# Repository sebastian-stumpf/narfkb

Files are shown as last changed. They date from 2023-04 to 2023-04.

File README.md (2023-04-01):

# narfkb

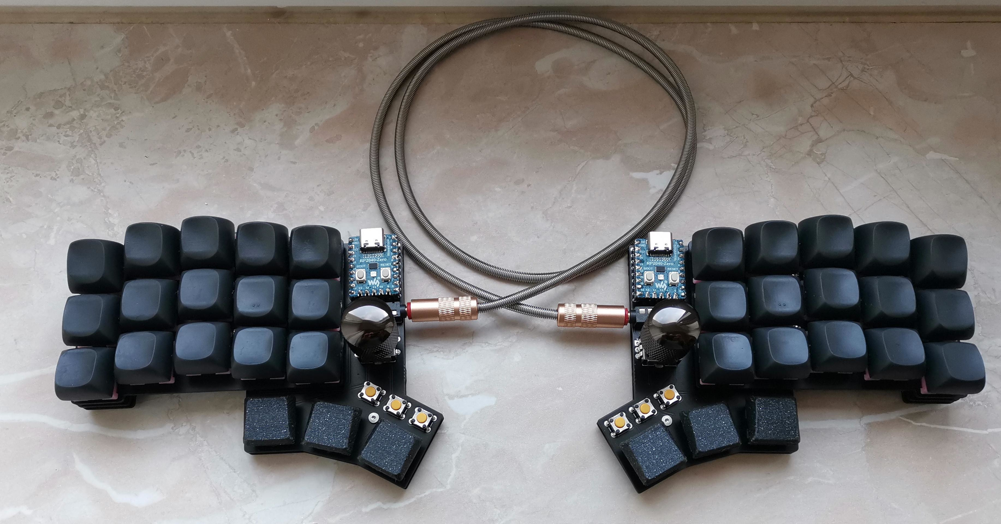
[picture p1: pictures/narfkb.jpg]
narfkb


[More pictures here](https://imgur.com/a/LNFxImS)

## Attention

I'm a hobbyist/amateur at best. So there may be things that aren't optimized. For example the routing on the PCB is a hot mess
and the spacers between the plate should be 3.4mm but there aren't any spacers that size. That being said I've had the files
in the `gerbers/` directory manufactured at JLC with 1.6mm size and they work just fine with the code provided in the `qmk/`
directory. So if you decide to use this, then please be advised that I'm not providing any sort of liability and you should
exercise some caution.

## BOM

| Quantity  | Item | Comment |
| --- | --- | --- |
| 2 | Waveshare RP2040-Zero | |
| 2 | IC-Sockets for MCU | Optional but recommended |
| 2 | TRRS Sockets | |
| 44 | 1N4148 SOD123 diodes | |
| 30 | MX Hotswap Sockets | |
| 6 | Choc Hotswap Sockets | |
| 2 | EC11 Encoders | |
| 6 | Omrom 6mm Tact switches | B3F-1002 |
| 30 | MX Switches + Keycaps | |
| 6 | Choc Switches + Keycaps | |
| 12 | M2 Screws, Nuts, Bolts and Spacers | |

## Feedback

I'm always happy to hear your opinions about this and if you decide to build this board then please do send me a picture of it.

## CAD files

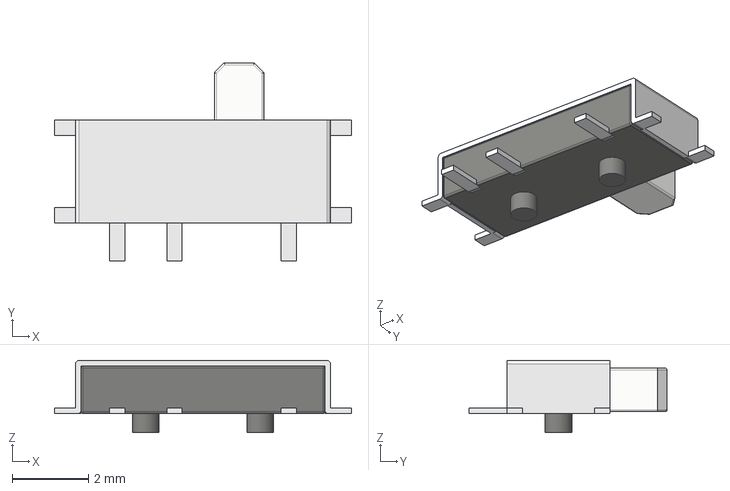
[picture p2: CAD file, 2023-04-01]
pcb/sepp/models/MSK12C02.step
7.80 x 5.20 x 1.90 mm

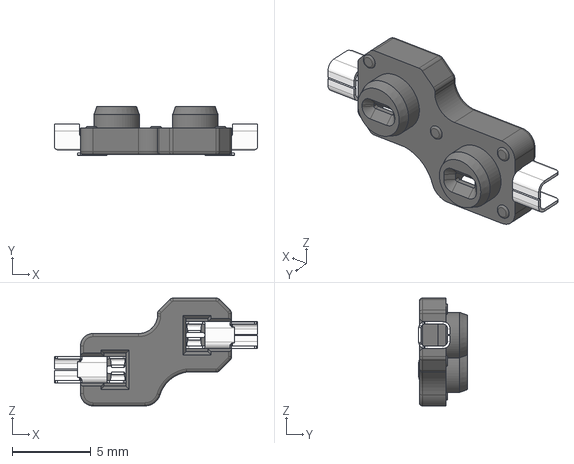
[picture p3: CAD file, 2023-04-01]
pcb/sepp/models/HS_Kailh_Choc.step
12.9 x 3.09 x 6.85 mm
pin x 2
socket

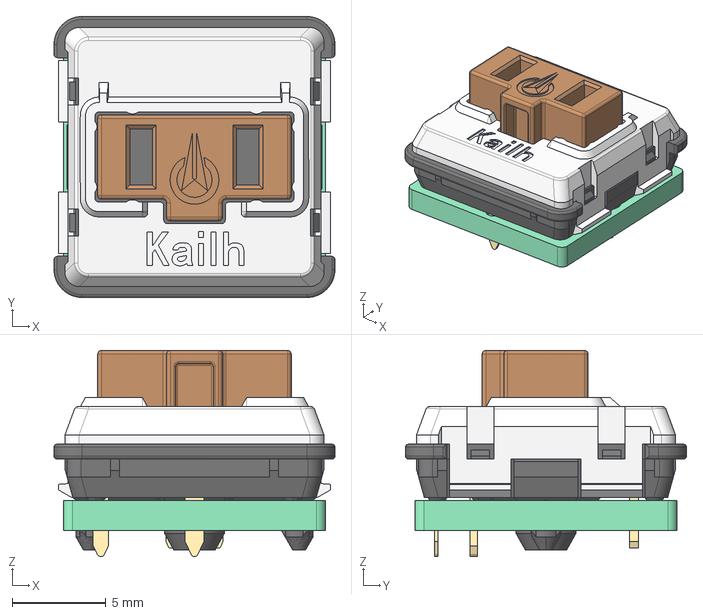
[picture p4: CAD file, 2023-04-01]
pcb/sepp/models/pg1350.step
15.0 x 15.0 x 11.0 mm

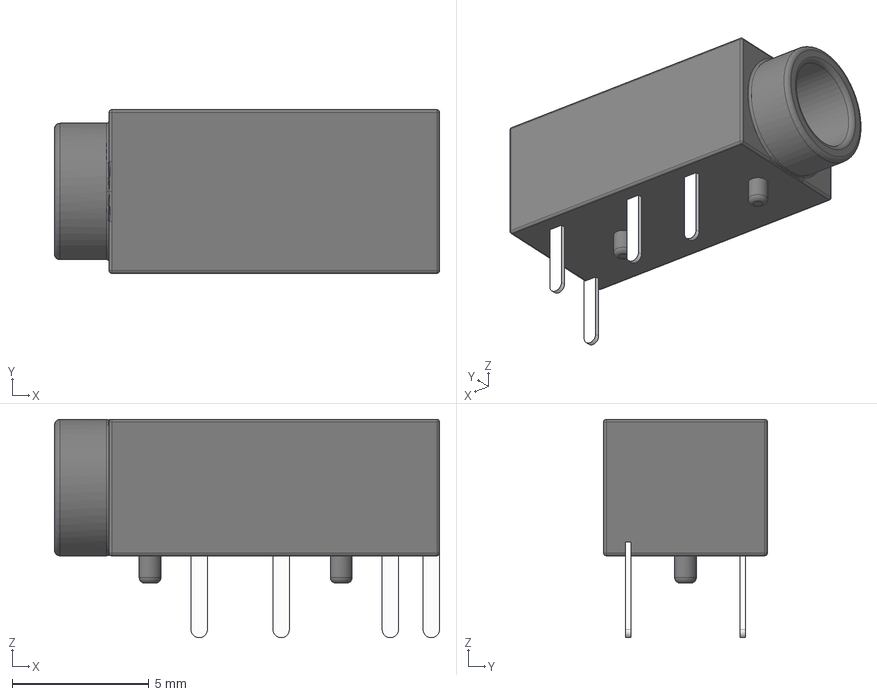
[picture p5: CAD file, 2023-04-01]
pcb/sepp/models/CON_MJ-4PP-9.step
14.1 x 6.00 x 8.00 mm

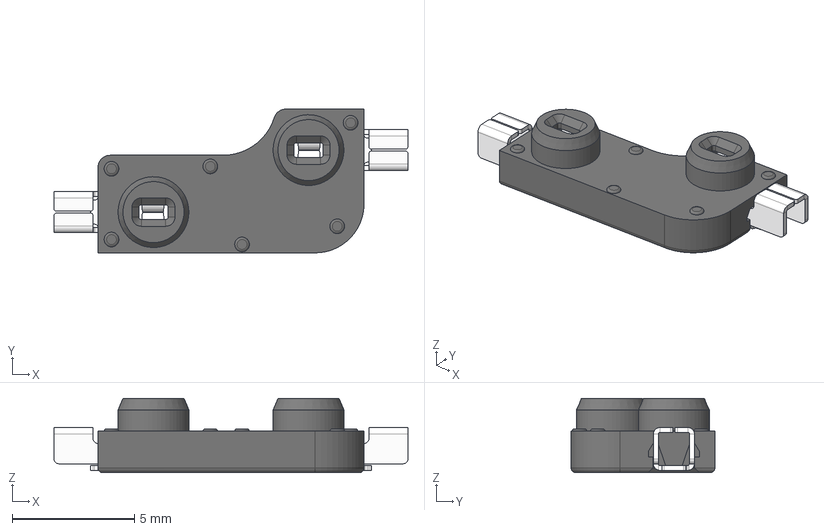
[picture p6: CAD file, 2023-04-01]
pcb/sepp/models/HS_Kailh_MX.step
14.5 x 5.89 x 3.05 mm
Contact x 2

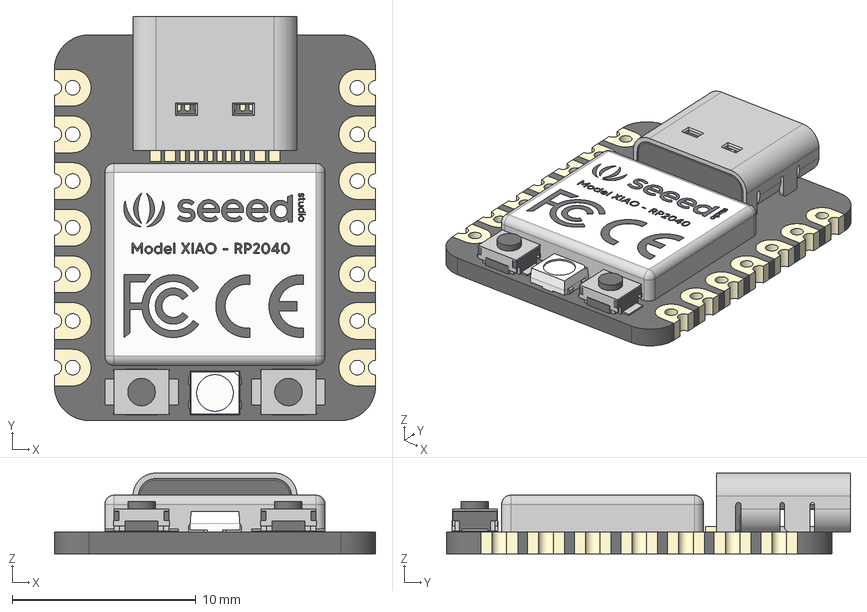
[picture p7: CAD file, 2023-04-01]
pcb/sepp/models/xiao_rp2040.step
17.5 x 22.0 x 4.40 mm
type-c v2
smd_button v3
DOUT
DIN
VSS
VDD
smd_button v3(Mirror)

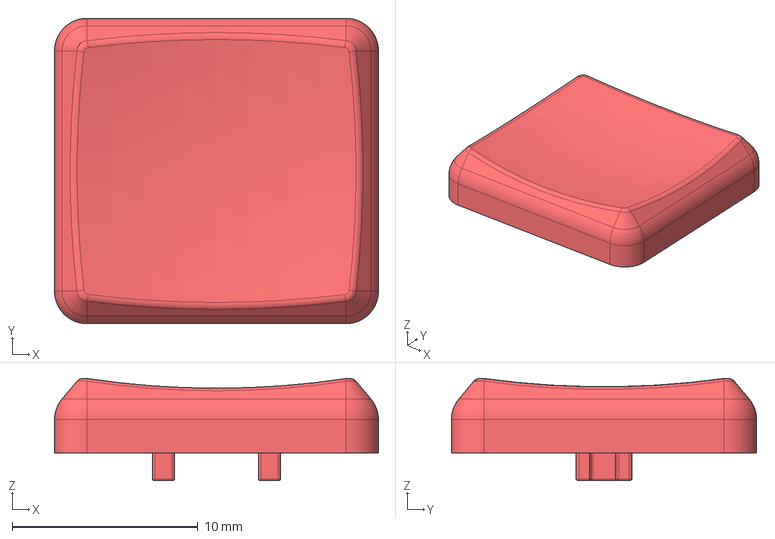
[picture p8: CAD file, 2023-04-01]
pcb/sepp/models/MBK-1u.step
17.4 x 16.4 x 5.52 mm

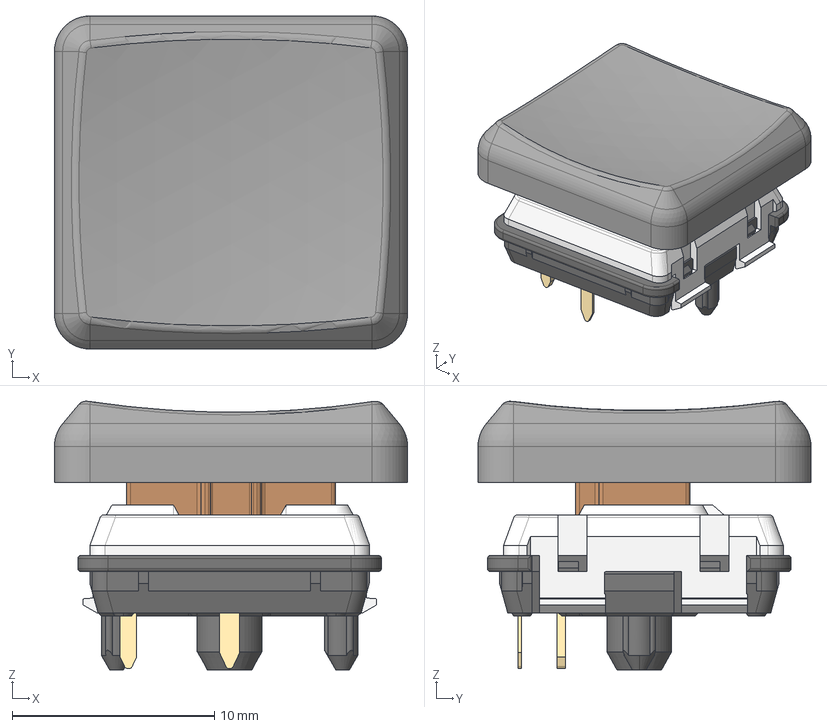
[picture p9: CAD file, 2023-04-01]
pcb/sepp/models/pg1350-mbk.step
17.4 x 16.4 x 13.3 mm
(Unsaved)
Document x 5

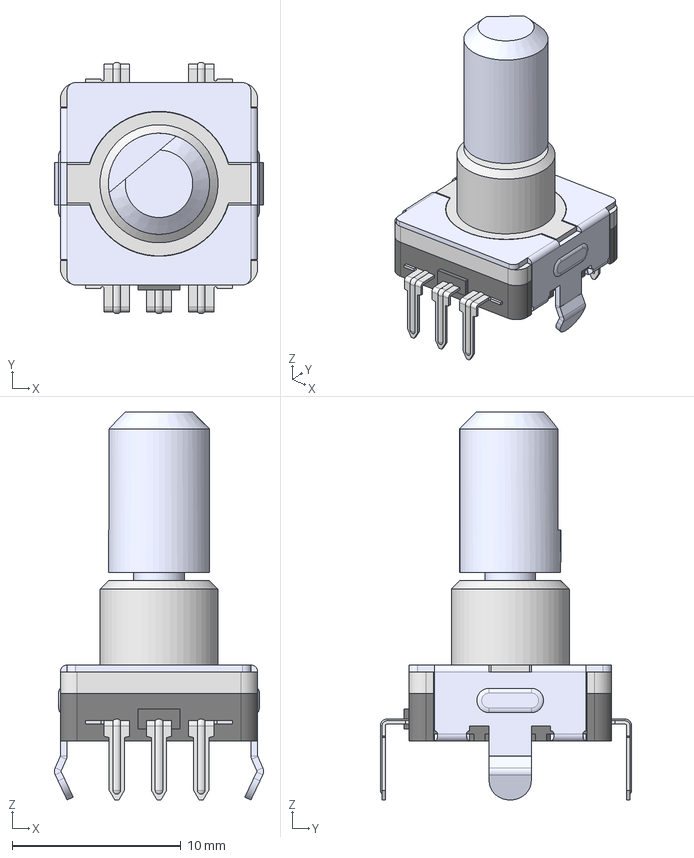
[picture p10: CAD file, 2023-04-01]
pcb/sepp/models/EC11-THT-15F-black.step
12.4 x 14.9 x 23.0 mm
Lb5
15F
EC11-Housing-THT

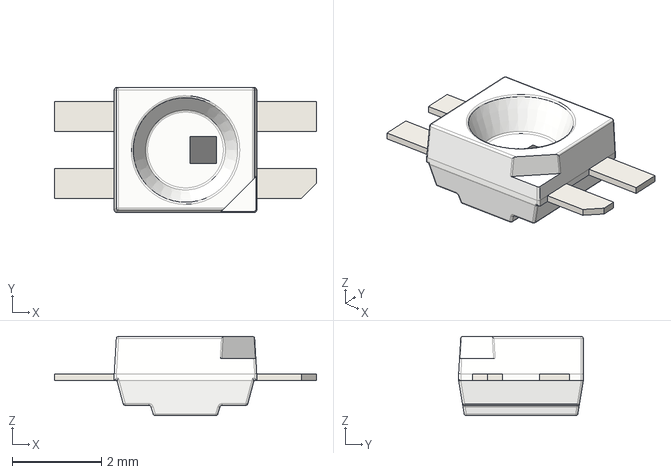
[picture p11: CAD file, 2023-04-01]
pcb/sepp/models/LED_SK6812MINI-E.step
5.88 x 2.80 x 1.78 mm

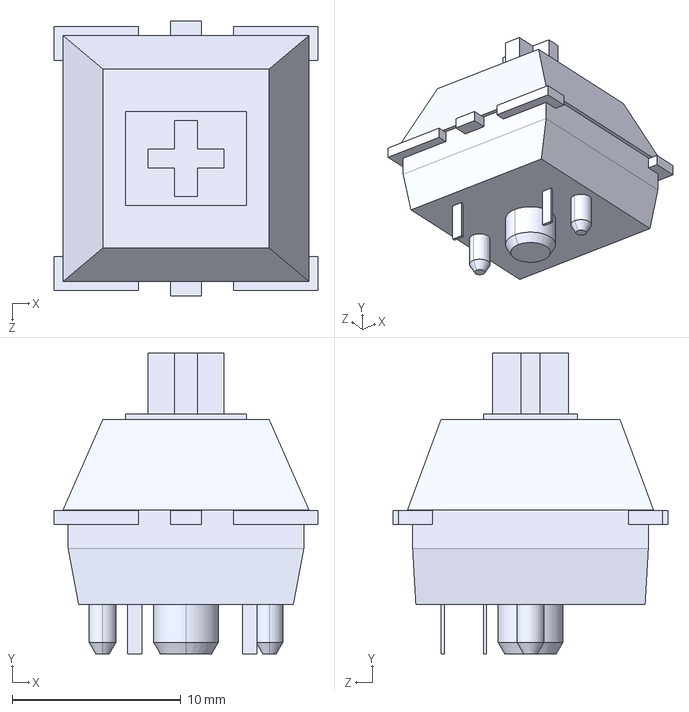
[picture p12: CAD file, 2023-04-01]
pcb/sepp/models/cherry mx.STEP
15.6 x 17.9 x 16.3 mm

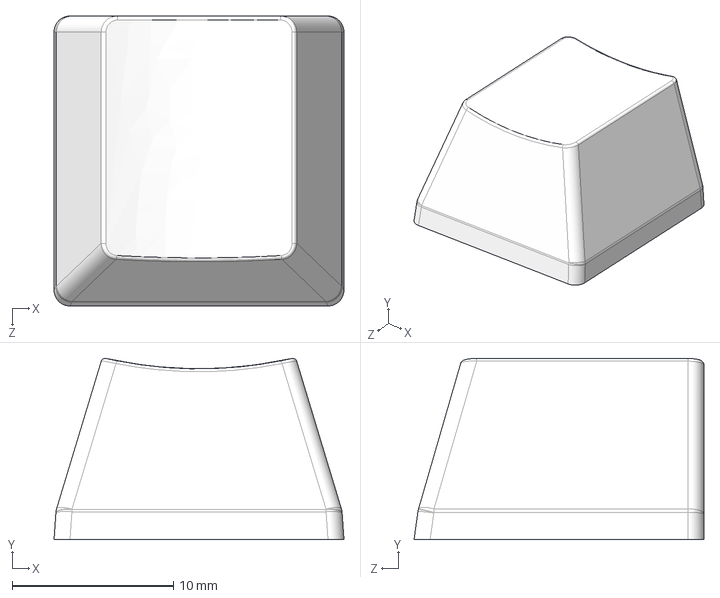
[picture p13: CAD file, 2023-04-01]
pcb/sepp/models/mx_kecap.step
18.0 x 11.3 x 18.0 mm

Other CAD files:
pcb/sepp/models/SW_MSK12C02.step

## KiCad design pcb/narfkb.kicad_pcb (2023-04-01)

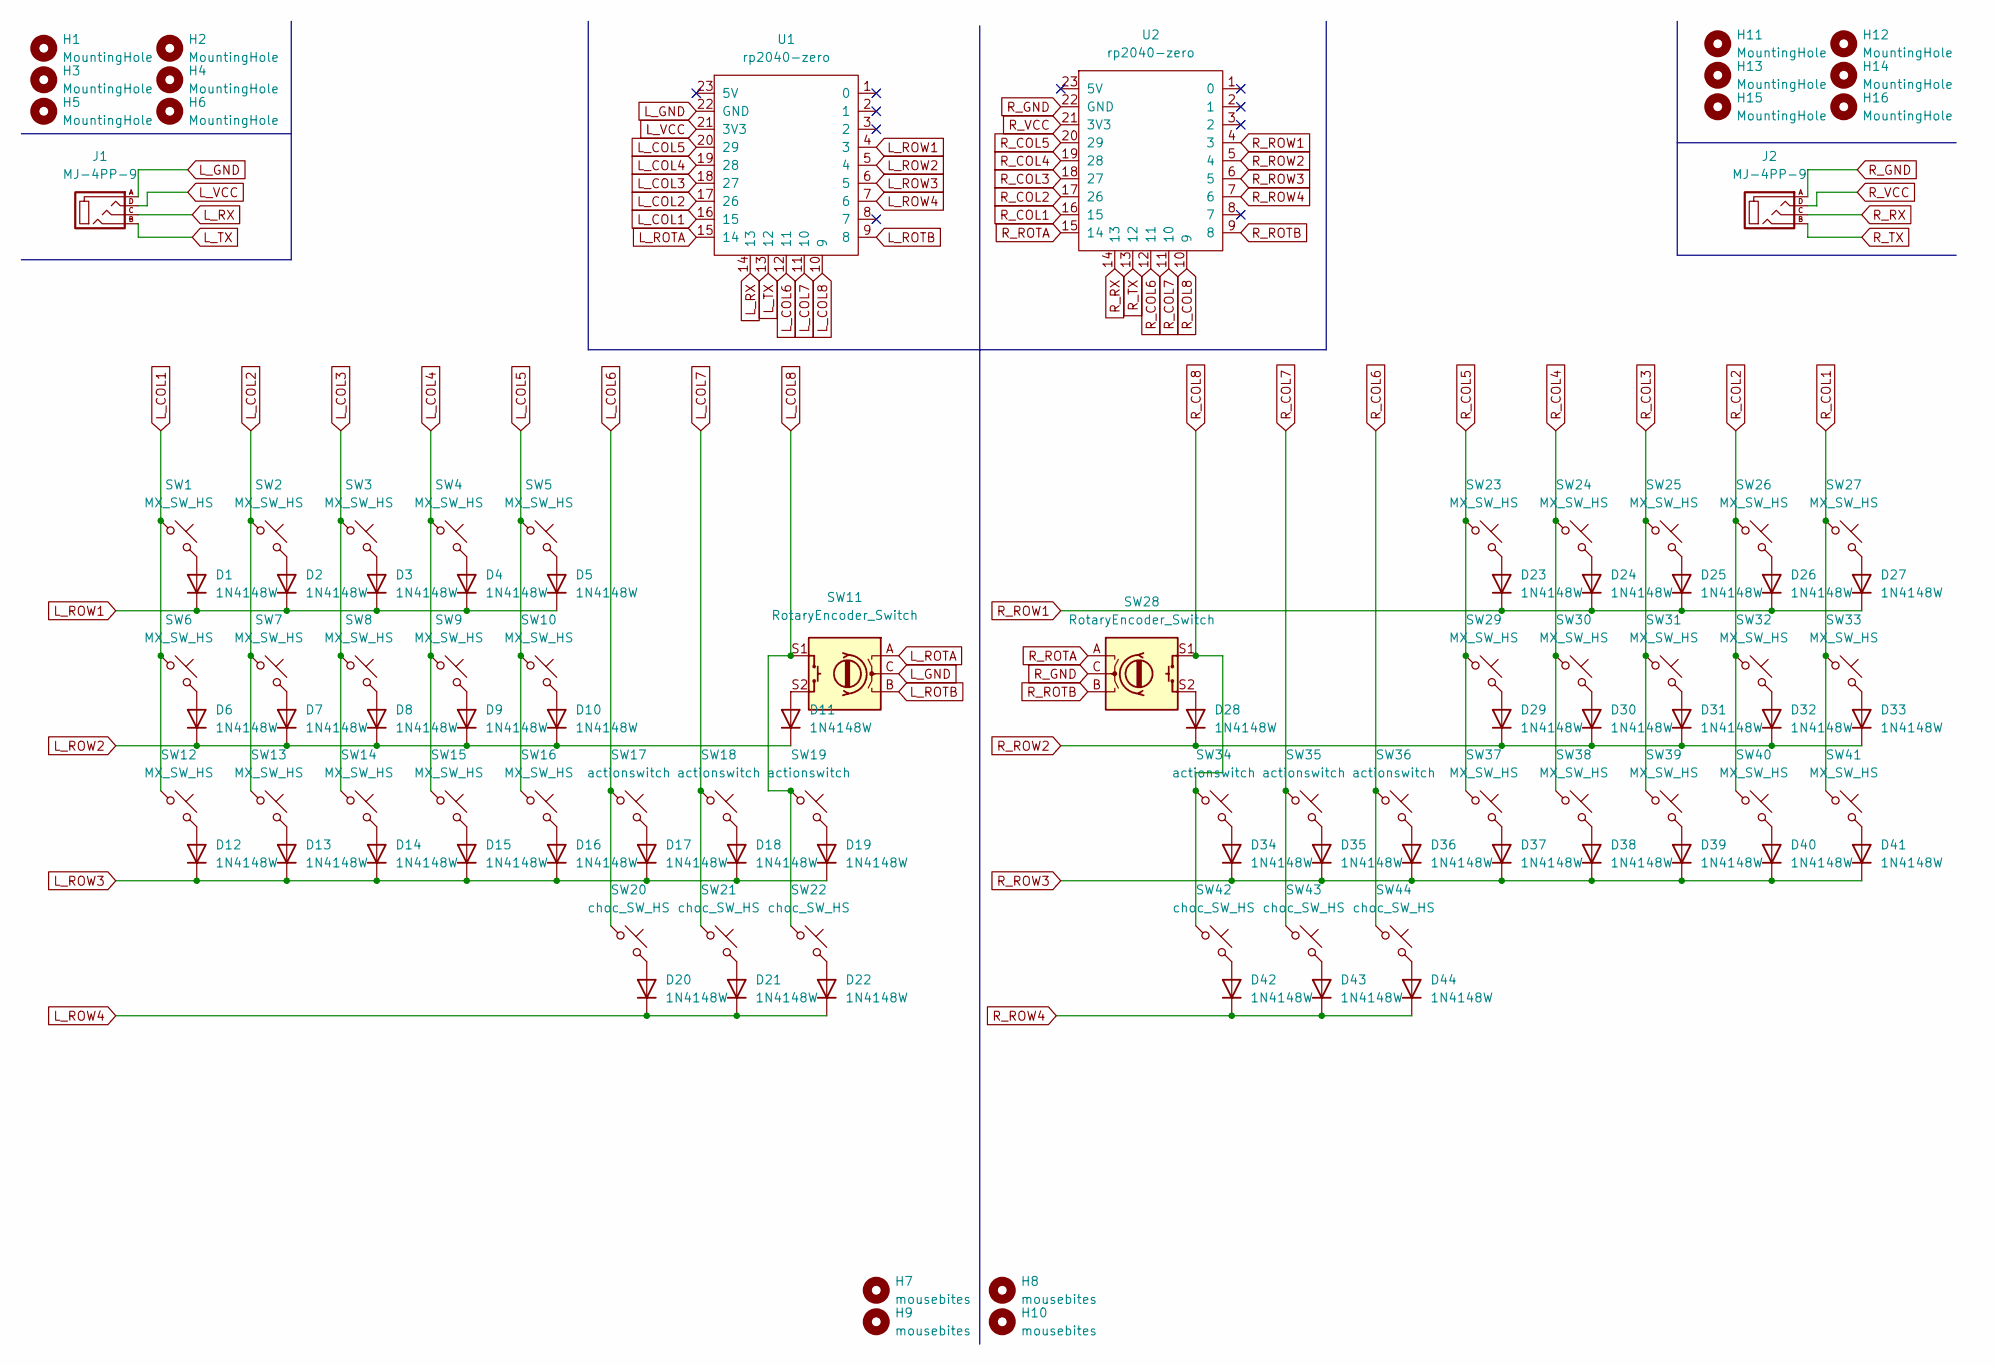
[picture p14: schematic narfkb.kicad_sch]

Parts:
D1, D2, D3, D4, D5, D6, D7, D8, D9, D10, D11, D12, D13, D14, D15, D16, D17, D18, D19, D20, D21, D22, D23, D24, D25, D26, D27, D28, D29, D30, D31, D32, D33, D34, D35, D36, D37, D38, D39, D40, D41, D42, D43, D44: 1N4148W; D_SOD-123
H1, H2, H3, H4, H5, H6, H11, H12, H13, H14, H15, H16: MountingHole; MountingHole_2.2mm_M2
H7, H8, H9, H10: mousebites; breakaway-mousebites
J1, J2: MJ-4PP-9
SW1, SW2, SW3, SW4, SW5, SW6, SW7, SW8, SW9, SW10, SW12, SW13, SW14, SW15, SW16, SW23, SW24, SW25, SW26, SW27, SW29, SW30, SW31, SW32, SW33, SW37, SW38, SW39, SW40, SW41: MX_SW_HS; SW_MX_HS_1u
SW11, SW28: RotaryEncoder_Switch; RotaryEncoder_EC11
SW17, SW18, SW19, SW34, SW35, SW36: actionswitch
SW20, SW21, SW22, SW42, SW43, SW44: choc_SW_HS; SW_choc_HS_1u
U1, U2: rp2040-zero; rp2040-zero-tht

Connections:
L_COL1: SW1.1, SW6.1, SW12.1, U1.16 (15)
L_COL2: SW2.1, SW7.1, SW13.1, U1.17 (26)
L_COL3: SW3.1, SW8.1, SW14.1, U1.18 (27)
L_COL4: SW4.1, SW9.1, SW15.1, U1.19 (28)
L_COL5: SW5.1, SW10.1, SW16.1, U1.20 (29)
L_COL6: SW17.1, SW20.1, U1.12 (11)
L_COL7: SW18.1, SW21.1, U1.11 (10)
L_COL8: SW11.S1, SW19.1, SW22.1, U1.10 (9)
L_GND: J1.A, SW11.C, U1.22 (GND)
L_ROTA: SW11.A, U1.15 (14)
L_ROTB: SW11.B, U1.9 (8)
L_ROW1: D1.1 (K), D2.1 (K), D3.1 (K), D4.1 (K), D5.1 (K), U1.4 (3)
L_ROW2: D6.1 (K), D7.1 (K), D8.1 (K), D9.1 (K), D10.1 (K), D11.1 (K), U1.5 (4)
L_ROW3: D12.1 (K), D13.1 (K), D14.1 (K), D15.1 (K), D16.1 (K), D17.1 (K), D18.1 (K), D19.1 (K), U1.6 (5)
L_ROW4: D20.1 (K), D21.1 (K), D22.1 (K), U1.7 (6)
L_RX: J1.C, U1.14 (13)
L_TX: J1.B, U1.13 (12)
L_VCC: J1.D, U1.21 (3V3)
unnamed: D1.2 (A), SW1.2
unnamed: D2.2 (A), SW2.2
unnamed: D3.2 (A), SW3.2
unnamed: D4.2 (A), SW4.2
unnamed: D5.2 (A), SW5.2
unnamed: D6.2 (A), SW6.2
unnamed: D7.2 (A), SW7.2
unnamed: D8.2 (A), SW8.2
unnamed: D9.2 (A), SW9.2
unnamed: D10.2 (A), SW10.2
unnamed: D11.2 (A), SW11.S2
unnamed: D12.2 (A), SW12.2
unnamed: D13.2 (A), SW13.2
unnamed: D14.2 (A), SW14.2
unnamed: D15.2 (A), SW15.2
unnamed: D16.2 (A), SW16.2
unnamed: D17.2 (A), SW17.2
unnamed: D18.2 (A), SW18.2
unnamed: D19.2 (A), SW19.2
unnamed: D20.2 (A), SW20.2
unnamed: D21.2 (A), SW21.2
unnamed: D22.2 (A), SW22.2
unnamed: D23.2 (A), SW23.2
unnamed: D24.2 (A), SW24.2
unnamed: D25.2 (A), SW25.2
unnamed: D26.2 (A), SW26.2
unnamed: D27.2 (A), SW27.2
unnamed: D28.2 (A), SW28.S2
unnamed: D29.2 (A), SW29.2
unnamed: D30.2 (A), SW30.2
unnamed: D31.2 (A), SW31.2
unnamed: D32.2 (A), SW32.2
unnamed: D33.2 (A), SW33.2
unnamed: D34.2 (A), SW34.2
unnamed: D35.2 (A), SW35.2
unnamed: D36.2 (A), SW36.2
unnamed: D37.2 (A), SW37.2
unnamed: D38.2 (A), SW38.2
unnamed: D39.2 (A), SW39.2
unnamed: D40.2 (A), SW40.2
unnamed: D41.2 (A), SW41.2
unnamed: D42.2 (A), SW42.2
unnamed: D43.2 (A), SW43.2
unnamed: D44.2 (A), SW44.2
R_COL1: SW27.1, SW33.1, SW41.1, U2.16 (15)
R_COL2: SW26.1, SW32.1, SW40.1, U2.17 (26)
R_COL3: SW25.1, SW31.1, SW39.1, U2.18 (27)
R_COL4: SW24.1, SW30.1, SW38.1, U2.19 (28)
R_COL5: SW23.1, SW29.1, SW37.1, U2.20 (29)
R_COL6: SW36.1, SW44.1, U2.12 (11)
R_COL7: SW35.1, SW43.1, U2.11 (10)
R_COL8: SW28.S1, SW34.1, SW42.1, U2.10 (9)
R_GND: J2.A, SW28.C, U2.22 (GND)
R_ROTA: SW28.A, U2.15 (14)
R_ROTB: SW28.B, U2.9 (8)
R_ROW1: D23.1 (K), D24.1 (K), D25.1 (K), D26.1 (K), D27.1 (K), U2.4 (3)
R_ROW2: D28.1 (K), D29.1 (K), D30.1 (K), D31.1 (K), D32.1 (K), D33.1 (K), U2.5 (4)
R_ROW3: D34.1 (K), D35.1 (K), D36.1 (K), D37.1 (K), D38.1 (K), D39.1 (K), D40.1 (K), D41.1 (K), U2.6 (5)
R_ROW4: D42.1 (K), D43.1 (K), D44.1 (K), U2.7 (6)
R_RX: J2.C, U2.14 (13)
R_TX: J2.B, U2.13 (12)
R_VCC: J2.D, U2.21 (3V3)

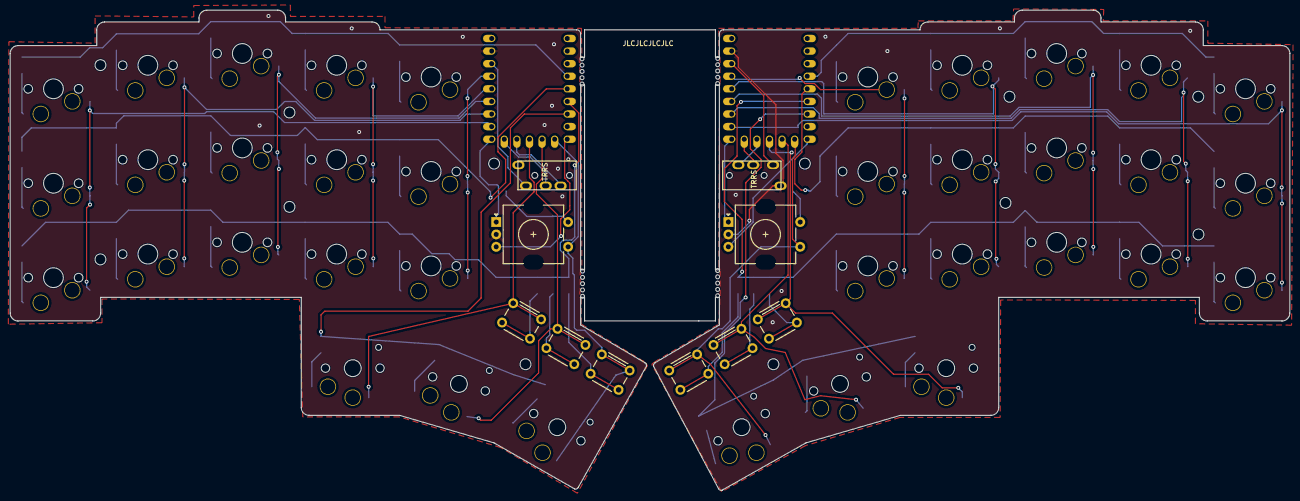
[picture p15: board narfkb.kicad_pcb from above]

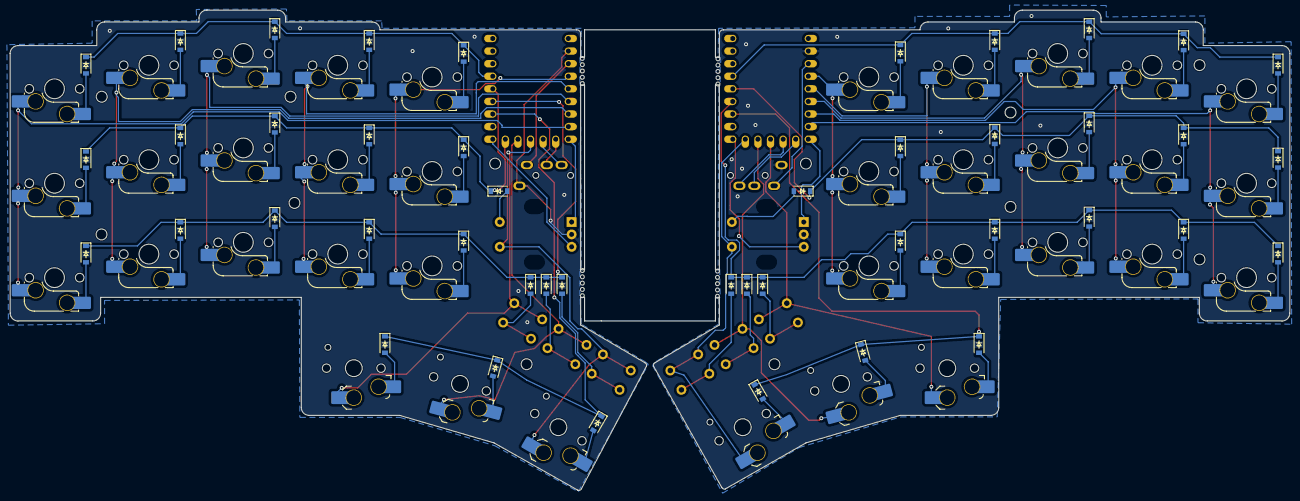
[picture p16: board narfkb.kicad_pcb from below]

Board: 2 copper layers, 258.2 x 96.9 mm, 108 parts (44 on the bottom side), 80 nets.

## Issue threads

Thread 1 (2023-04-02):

License?

BigBlueHat, 2023-04-02:
This looks like a great little board! What's the license for the files if I'd like to print my own?

Thanks for sharing!
🎩

sebastian-stumpf, 2023-04-07:
That's a good point. Thank you. I've added the MIT license file here: https://github.com/sebastian-stumpf/narfkb/commit/60071629ff74435773e6028236189e77b4fad2c3

BigBlueHat, 2023-04-07:
Thanks!

Closed 2023-04-07.

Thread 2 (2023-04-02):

Swap socket types

BigBlueHat, 2023-04-02:
Would it be possible to build this with MX for the thumbs and Chocs for the alphas? That would get it closer to a profile like the [ThumbsUp!](https://thumbsup.shop/) which I now use and find pretty comfortable personally.

Just a curious idea. 😄
🎩

sebastian-stumpf, 2023-04-07:
Currently unlikely. The switch footprints don't match. You'd have to swap the footprints and probably adjust the routing a bit for every switch.

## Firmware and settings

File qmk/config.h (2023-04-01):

#pragma once

#define DIODE_DIRECTION COL2ROW
#define MATRIX_ROWS 8
#define MATRIX_COLS 8

#define SPLIT_USB_DETECT
#define USE_SERIAL

// If you don't want to use full duplex you can specify GP12/GP13 below and use the remaining
// pin for somehting else
// #define SOFT_SERIAL_PIN GP13
// #define SERIAL_PIO_USE_PIO1

#define SERIAL_USART_FULL_DUPLEX
#define SERIAL_USART_TX_PIN GP12
#define SERIAL_USART_RX_PIN GP13
#define SERIAL_USART_PIN_SWAP

#define MATRIX_ROW_PINS { GP3, GP4, GP5, GP6 }
#define MATRIX_COL_PINS { GP15, GP26, GP27, GP28, GP29, GP11, GP10, GP9 }

#define ENCODERS_PAD_A { GP14 }
#define ENCODERS_PAD_B { GP8 }

#define RP2040_BOOTLOADER_DOUBLE_TAP_RESET
#define RP2040_BOOTLOADER_DOUBLE_TAP_RESET_TIMEOUT 500U
